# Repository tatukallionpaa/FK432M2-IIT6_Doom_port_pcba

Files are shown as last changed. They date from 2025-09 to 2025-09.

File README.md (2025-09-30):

Kicad project files for STM32 doom port. Software repo in https://github.com/tatukallionpaa/stm32_h743_doom_port.

Based on FK743M2-IIT6 dev board. Video is outputted via VGA and a USB keyboard is used as an input.



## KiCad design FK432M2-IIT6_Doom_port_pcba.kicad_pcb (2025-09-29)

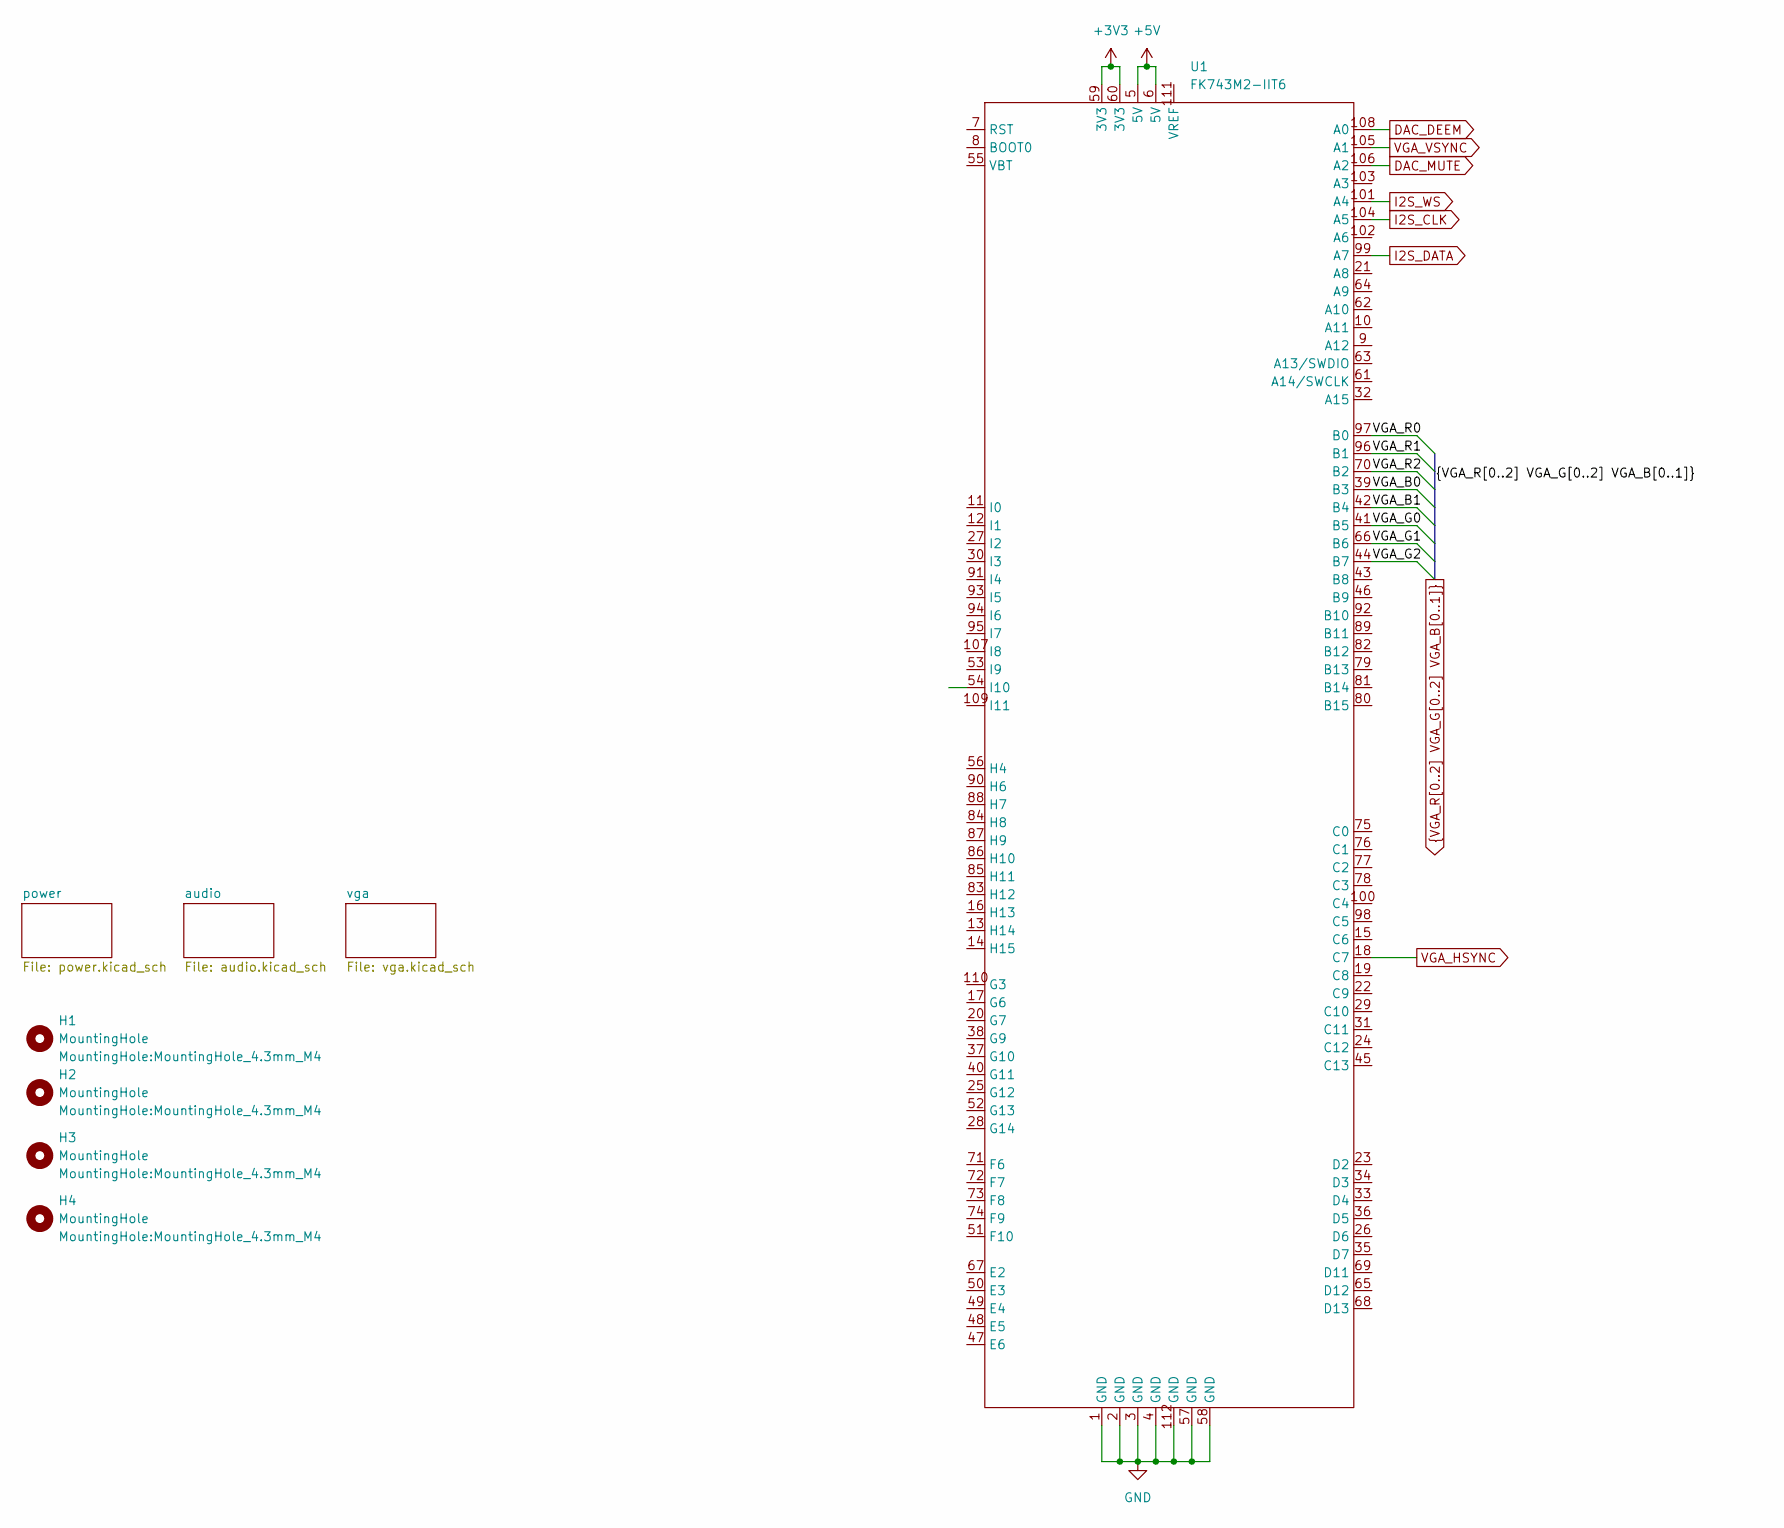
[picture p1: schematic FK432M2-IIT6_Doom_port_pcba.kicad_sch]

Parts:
H1, H2, H3, H4: MountingHole; MountingHole_4.3mm_M4
U1: FK743M2-IIT6; FK432M2-IIT6

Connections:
+3V3: U1.59 (3V3), U1.60 (3V3); also elsewhere on the board
+5V: U1.5 (5V), U1.6 (5V); also elsewhere on the board
DAC_DEEM: U1.108 (A0); also elsewhere on the board
DAC_MUTE: U1.106 (A2); also elsewhere on the board
GND: U1.1 (GND), U1.2 (GND), U1.3 (GND), U1.4 (GND), U1.57 (GND), U1.58 (GND), U1.112 (GND); also elsewhere on the board
I2S_CLK: U1.104 (A5); also elsewhere on the board
I2S_DATA: U1.99 (A7); also elsewhere on the board
I2S_WS: U1.101 (A4); also elsewhere on the board
VGA_B0: U1.39 (B3); also elsewhere on the board
VGA_B1: U1.42 (B4); also elsewhere on the board
VGA_G0: U1.41 (B5); also elsewhere on the board
VGA_G1: U1.66 (B6); also elsewhere on the board
VGA_G2: U1.44 (B7); also elsewhere on the board
VGA_HSYNC: U1.18 (C7); also elsewhere on the board
VGA_R0: U1.97 (B0); also elsewhere on the board
VGA_R1: U1.96 (B1); also elsewhere on the board
VGA_R2: U1.70 (B2); also elsewhere on the board
VGA_VSYNC: U1.105 (A1); also elsewhere on the board

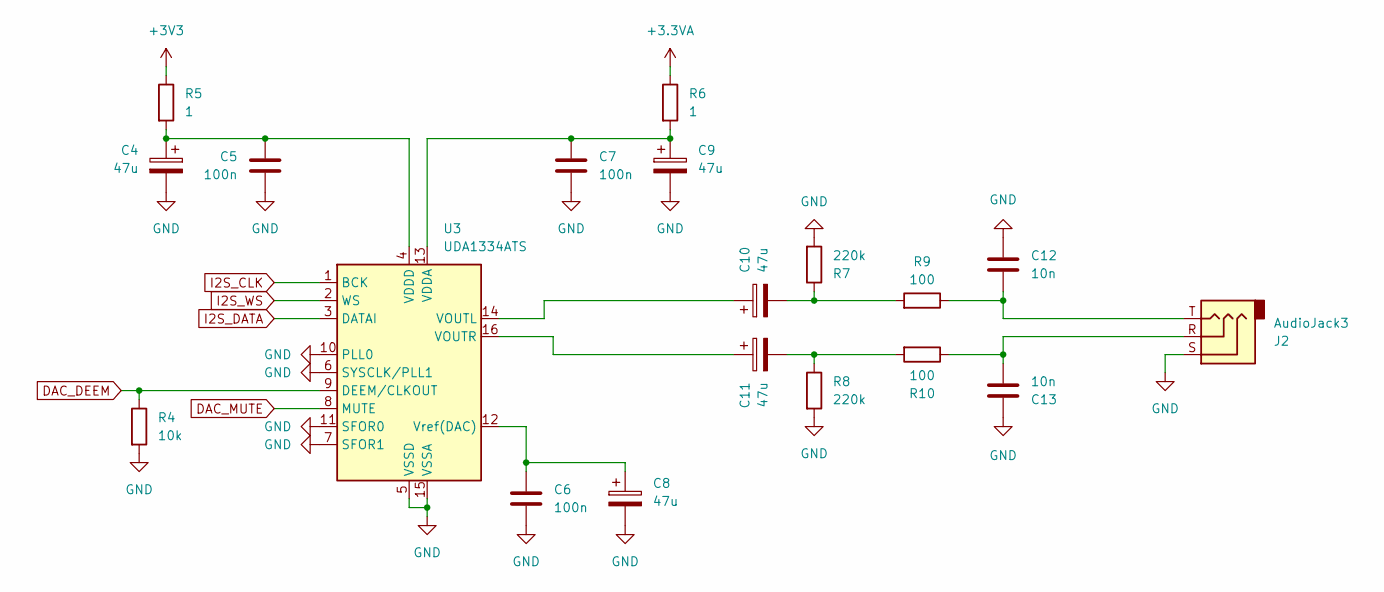
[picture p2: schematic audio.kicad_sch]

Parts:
C4, C8, C9, C10, C11: 47u; CP_Elec_5x5.4
C5, C6, C7: 100n; C_0805_2012Metric_Pad1.18x1.45mm_HandSolder
C12, C13: 10n; C_0805_2012Metric_Pad1.18x1.45mm_HandSolder
J2: AudioJack3; Jack_3.5mm_Lumberg_1503_07_Horizontal
R4: 10k; R_0805_2012Metric_Pad1.20x1.40mm_HandSolder
R5, R6: 1; R_0805_2012Metric_Pad1.20x1.40mm_HandSolder
R7, R8: 220k; R_0805_2012Metric_Pad1.20x1.40mm_HandSolder
R9, R10: 100; R_0805_2012Metric_Pad1.20x1.40mm_HandSolder
U3: UDA1334ATS; SSOP-16_4.4x5.2mm_P0.65mm

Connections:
+3.3VA: R6.1; also elsewhere on the board
+3V3: R5.1; also elsewhere on the board
DAC_DEEM: R4.1, U3.9 (DEEM/CLKOUT); also elsewhere on the board
DAC_MUTE: U3.8 (MUTE); also elsewhere on the board
GND: C4.2, C5.2, C6.2, C7.2, C8.2, C9.2, C12.1, C13.1, J2.S, R4.2, R7.2, R8.2, U3.5 (VSSD), U3.6 (SYSCLK/PLL1), U3.7 (SFOR1), U3.10 (PLL0), U3.11 (SFOR0), U3.15 (VSSA); also elsewhere on the board
I2S_CLK: U3.1 (BCK); also elsewhere on the board
I2S_DATA: U3.3 (DATAI); also elsewhere on the board
I2S_WS: U3.2 (WS); also elsewhere on the board
unnamed: C10.2, R7.1, R9.2
unnamed: C11.2, R8.1, R10.2
unnamed: C12.2, J2.T, R9.1
unnamed: C13.2, J2.R, R10.1
unnamed: C7.1, C9.1, R6.2, U3.13 (VDDA)
unnamed: C4.1, C5.1, R5.2, U3.4 (VDDD)
unnamed: C10.1, U3.14 (VOUTL)
unnamed: C11.1, U3.16 (VOUTR)
unnamed: C6.1, C8.1, U3.12 (Vref(DAC))

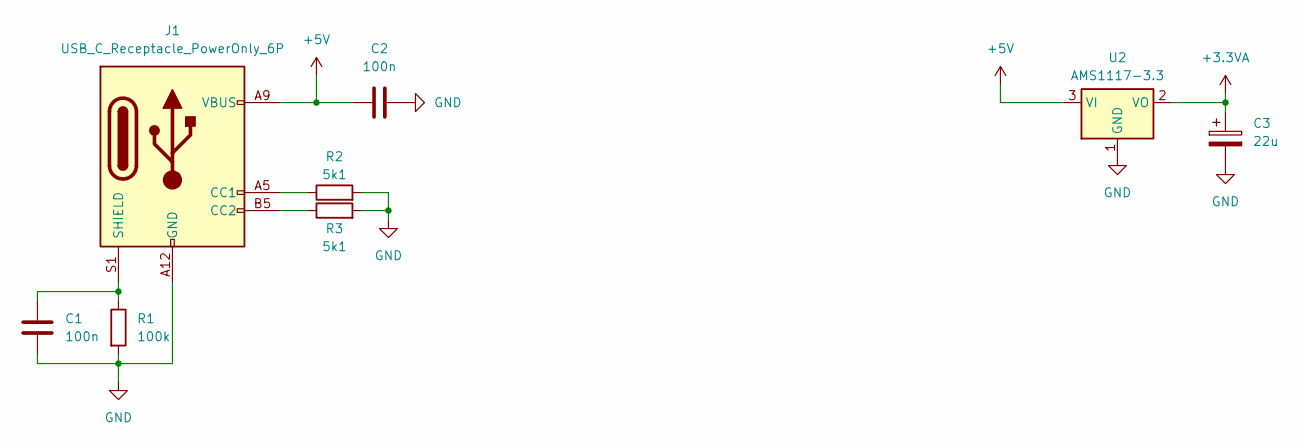
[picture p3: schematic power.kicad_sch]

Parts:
C1, C2: 100n; C_0805_2012Metric_Pad1.18x1.45mm_HandSolder
C3: 22u; CP_Elec_4x5.4
J1: USB_C_Receptacle_PowerOnly_6P; USB_C_Receptacle_GCT_USB4125-xx-x_6P_TopMnt_Horizontal
R1: 100k; R_0805_2012Metric_Pad1.20x1.40mm_HandSolder
R2, R3: 5k1; R_0805_2012Metric_Pad1.20x1.40mm_HandSolder
U2: AMS1117-3.3; SOT-223-3_TabPin2

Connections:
+3.3VA: C3.1, U2.2 (VO); also elsewhere on the board
+5V: C2.1, J1.A9 (VBUS), J1.B9 (VBUS), U2.3 (VI); also elsewhere on the board
GND: C1.2, C2.2, C3.2, J1.A12 (GND), J1.B12 (GND), R1.2, R2.2, R3.2, U2.1 (GND); also elsewhere on the board
unnamed: J1.A5 (CC1), R2.1
unnamed: J1.B5 (CC2), R3.1
unnamed: C1.1, J1.S1 (SHIELD), R1.1

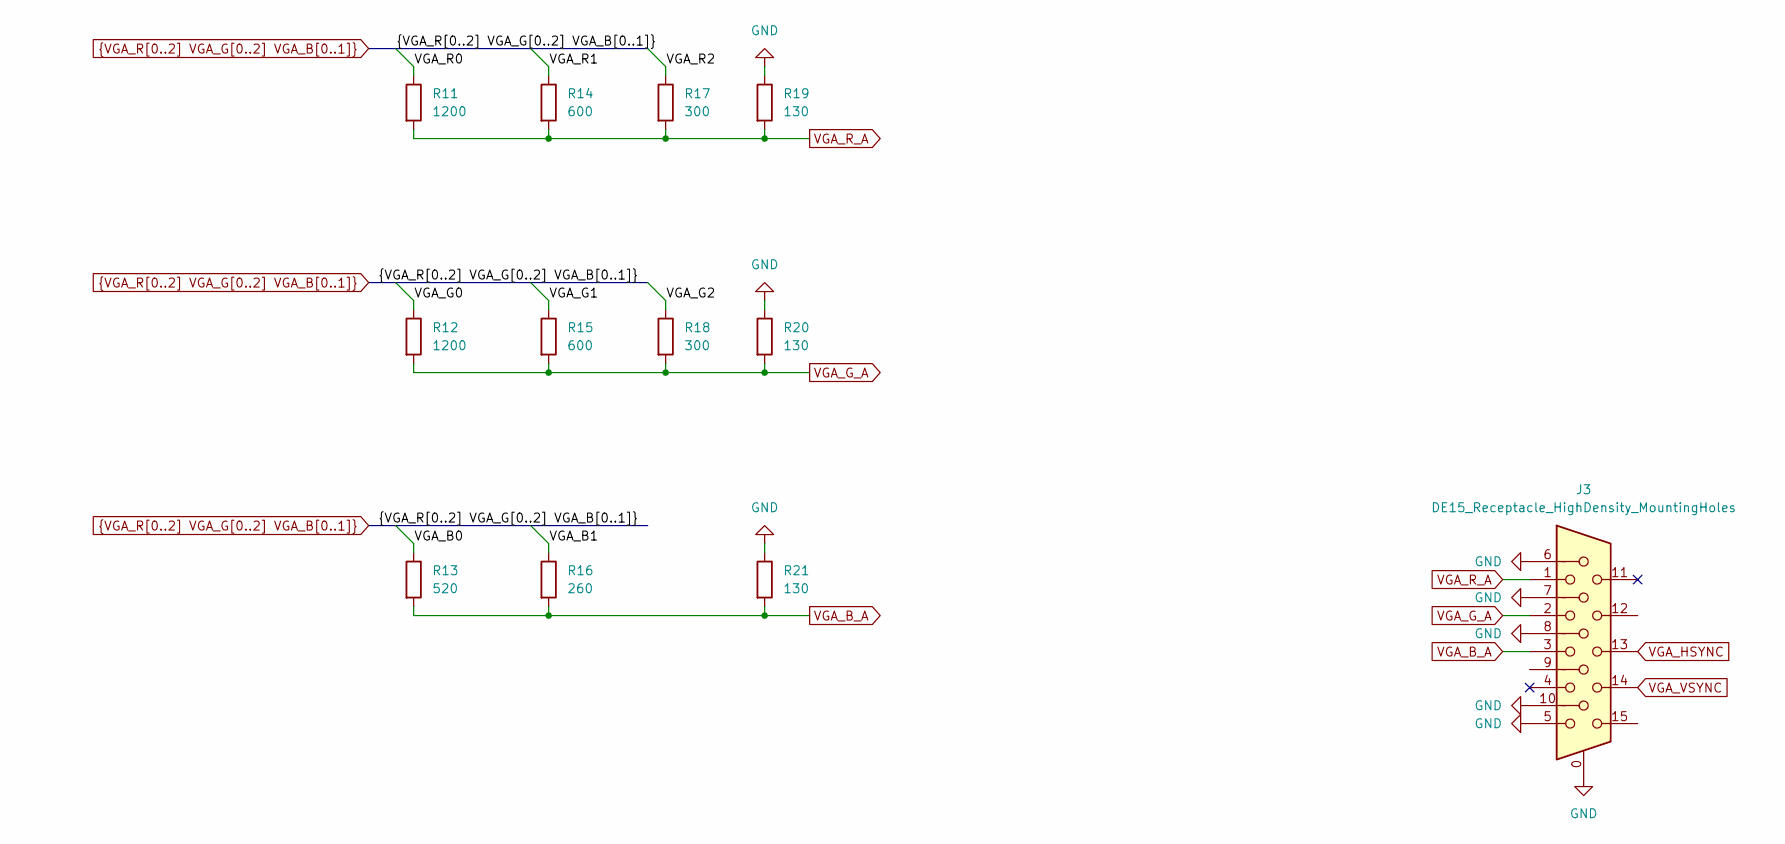
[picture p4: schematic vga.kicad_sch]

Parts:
J3: DE15_Receptacle_HighDensity_MountingHoles; DSUB-15-HD_Female_Horizontal_P2.29x1.98mm_EdgePinOffset3.03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
R11, R12: 1200; R_0805_2012Metric_Pad1.20x1.40mm_HandSolder
R13: 520; R_0805_2012Metric_Pad1.20x1.40mm_HandSolder
R14, R15: 600; R_0805_2012Metric_Pad1.20x1.40mm_HandSolder
R16: 260; R_0805_2012Metric_Pad1.20x1.40mm_HandSolder
R17, R18: 300; R_0805_2012Metric_Pad1.20x1.40mm_HandSolder
R19, R20, R21: 130; R_0805_2012Metric_Pad1.20x1.40mm_HandSolder

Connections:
GND: J3.0, J3.5, J3.6, J3.7, J3.8, J3.10, R19.1, R20.1, R21.1; also elsewhere on the board
VGA_B0: R13.1; also elsewhere on the board
VGA_B1: R16.1; also elsewhere on the board
VGA_B_A: J3.3, R13.2, R16.2, R21.2
VGA_G0: R12.1; also elsewhere on the board
VGA_G1: R15.1; also elsewhere on the board
VGA_G2: R18.1; also elsewhere on the board
VGA_G_A: J3.2, R12.2, R15.2, R18.2, R20.2
VGA_HSYNC: J3.13; also elsewhere on the board
VGA_R0: R11.1; also elsewhere on the board
VGA_R1: R14.1; also elsewhere on the board
VGA_R2: R17.1; also elsewhere on the board
VGA_R_A: J3.1, R11.2, R14.2, R17.2, R19.2
VGA_VSYNC: J3.14; also elsewhere on the board

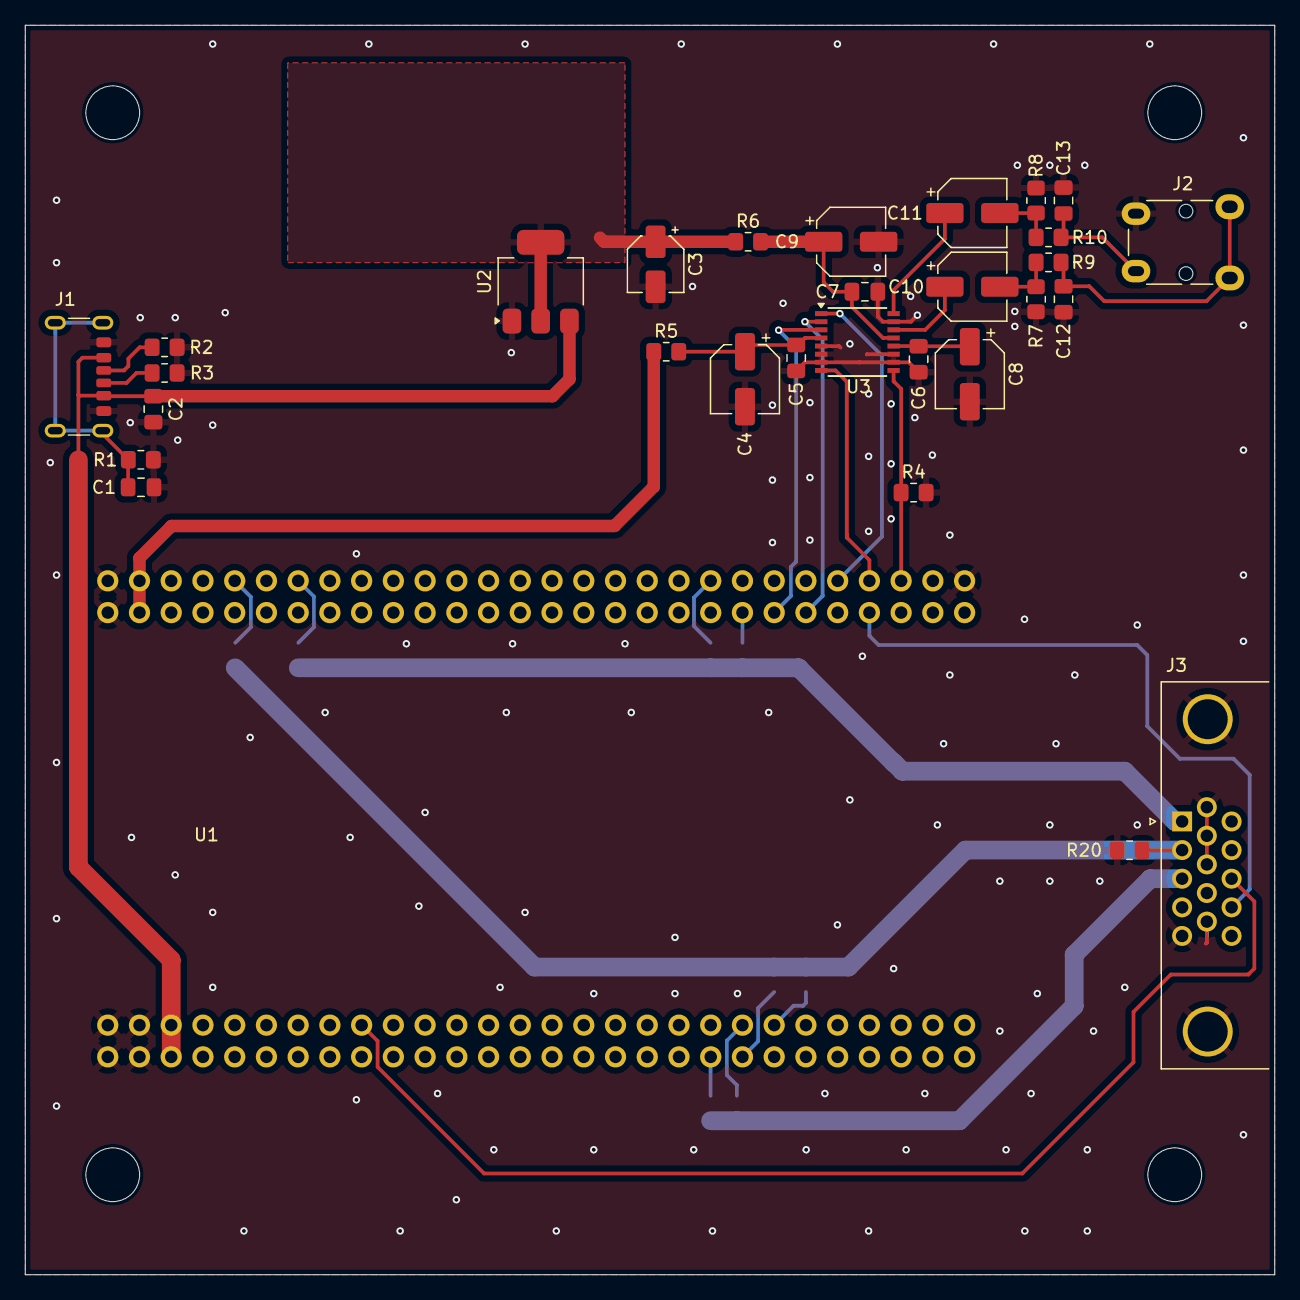
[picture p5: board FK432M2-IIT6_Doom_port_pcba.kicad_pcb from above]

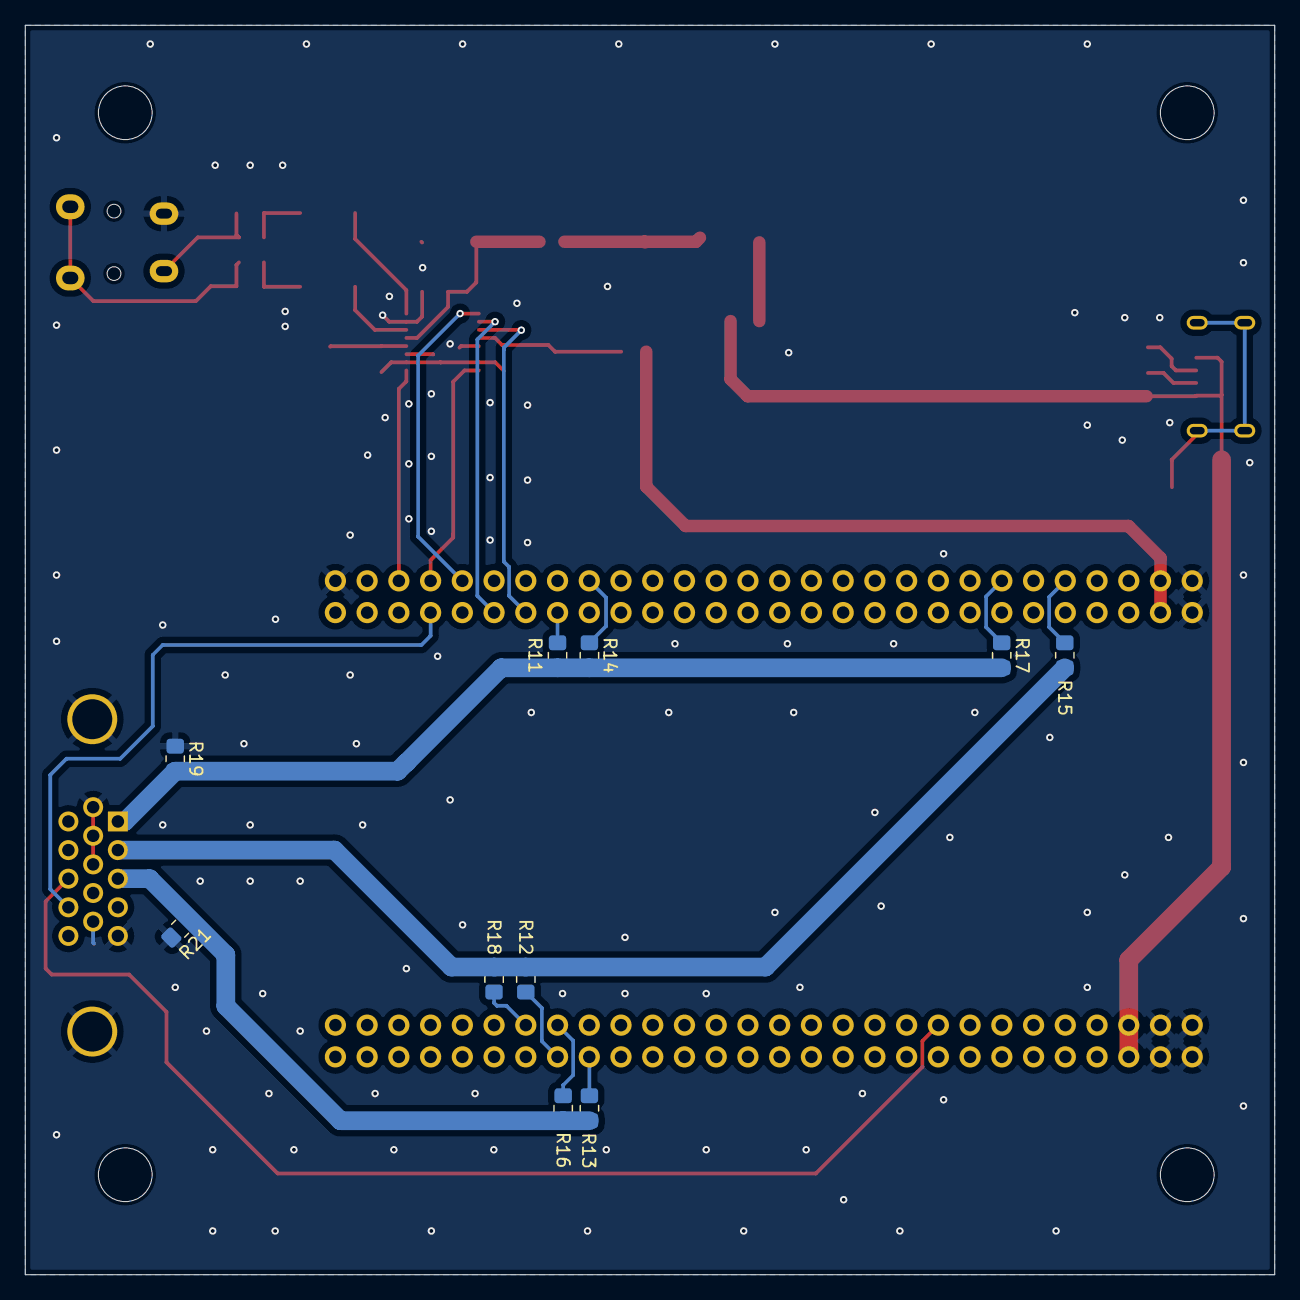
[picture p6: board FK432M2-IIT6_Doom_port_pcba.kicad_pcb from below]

Board: 2 copper layers, 100.0 x 100.0 mm, 44 parts (10 on the bottom side), 34 nets.
